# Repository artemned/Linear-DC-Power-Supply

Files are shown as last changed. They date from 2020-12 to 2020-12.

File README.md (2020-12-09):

# Linear-DC-Power-Supply
##  Board source dc voltage and dc current.   
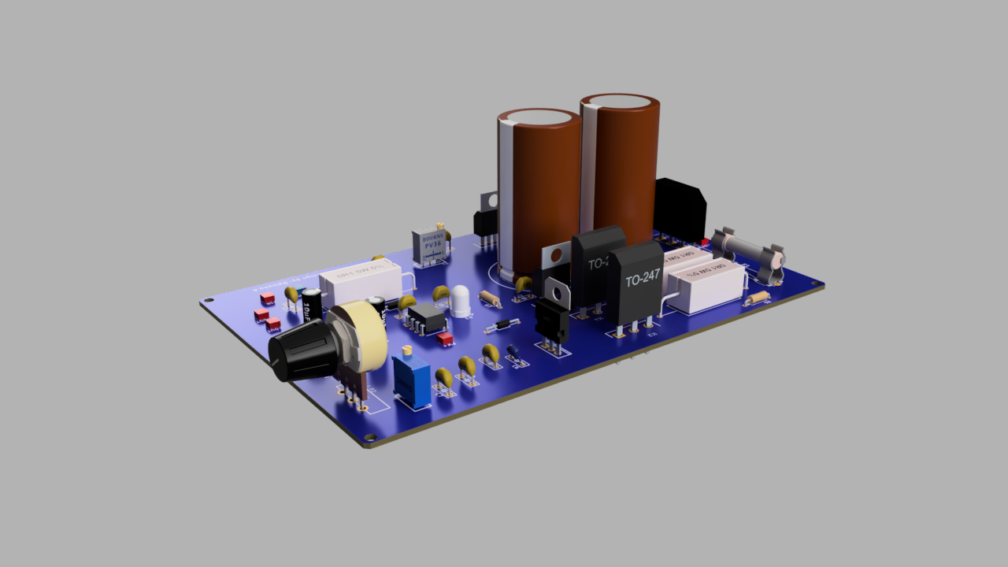
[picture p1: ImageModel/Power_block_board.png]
 

## One of the possible types power supplies
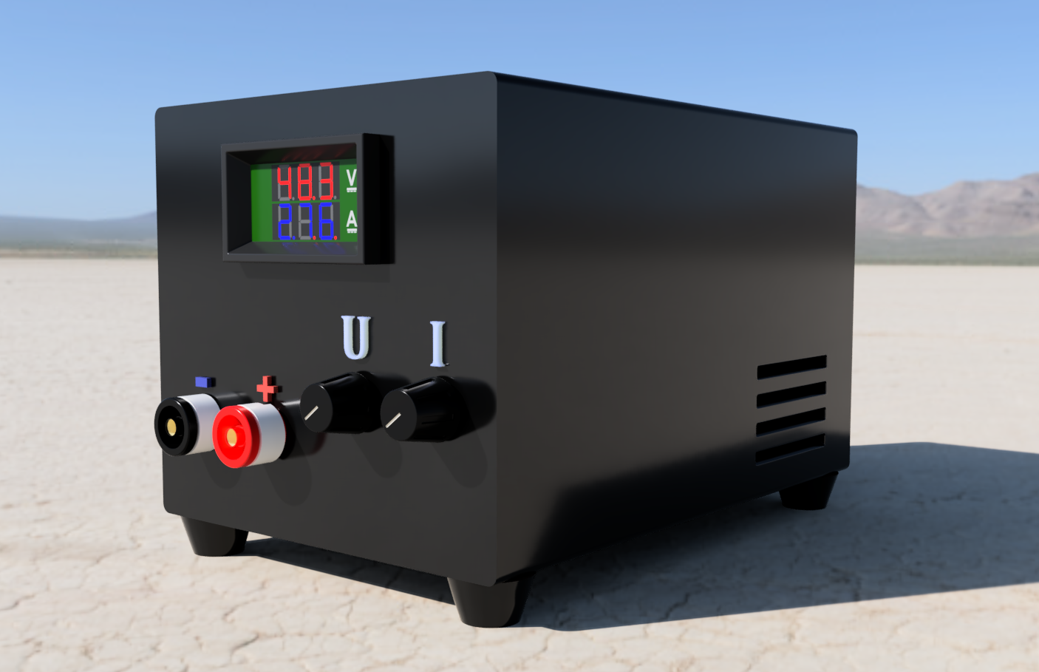
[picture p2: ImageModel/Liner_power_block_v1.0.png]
 
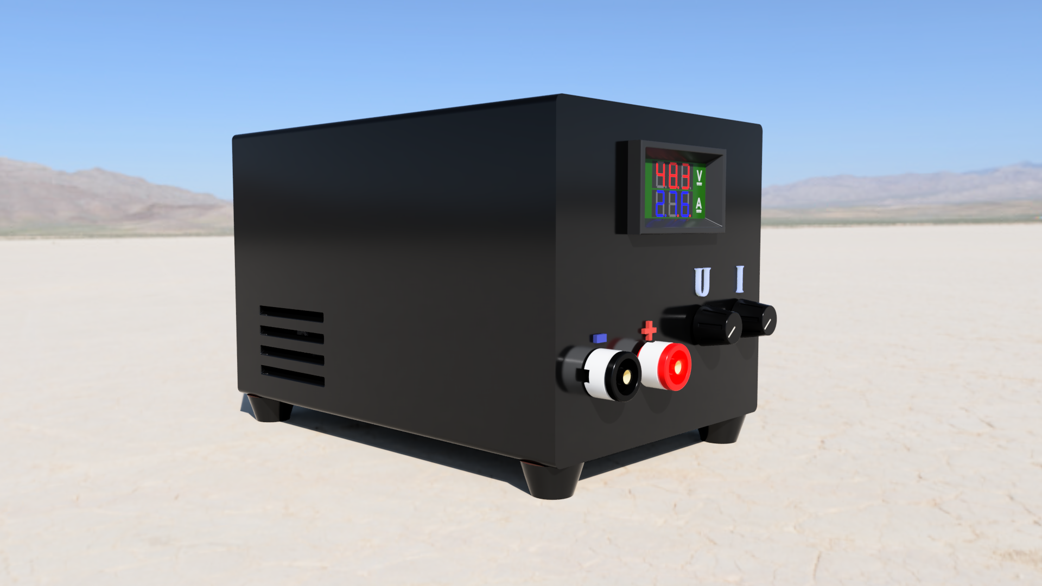
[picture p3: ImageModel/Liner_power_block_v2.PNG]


### I was inspired to create this project by the advice of my colleagues and the lack of a regulated DC voltage and DC power supply. I also wanted to practice PCB design. I used Eagle CAD for this. The project is based on one of the schematics in The Art of Circuitry by Paul Horowitz and Hill Winfield. There are many variants of this device on the network, but it seems to me that it is simpler and does not require many components. Of course, this scheme has a number of positive changes compared to the original. Everything you need to make a board and assemble a device is in the repository.I am sure that even a novice radio amateur will be able to assemble it, and if something suddenly does not work out, then write to the email address: daineko.a32@mail.ru.    P.S. All goodness and fresh cookies!

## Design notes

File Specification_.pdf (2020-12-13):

Part | Value | Package | Description
B1 | | FBU4 | Diode bridge GBU 8005
B2 | | FBU4 | Diode bridge GBU 8005
C1 | 10000uF | EB30D | Polarized capacitor
C2 | 10000uF | EB30D | Polarized capacitor
C3 | 68n | C050-025X075 | Capacitor
C4 | 0.33uF | C5B2.5 | Capacitor
C5 | 1.0uF | C050-025X075 | Capacitor
C6 | 100pF | C5B2.5 | Capacitor
C7 | 0.1uF | C5B2.5 | Capacitor
C8 | 100pF | C5B2.5 | Capacitor
C9 | 100pF | C5B2.5 | Capacitor
C10 | 10uF | CPOL-RADIAL-2.5MM-5MM | 10.0ВµF Polarized capacitors
C11 | 0.22uF | C5B2.5 | Capacitor
C12 | 10nF | C5B2.5 | Capacitor
C13 | 1000uF | EB22,5D | Polarized capacitor
C14 | 0.1uF | C5B2.5 | Capacitor
C15 | 10uF | CPOL-RADIAL-2.5MM-5MM | 10.0ВµF polarized capacitors
D1 | 1N5408RLG | DIOAD2860W130L840D505 | Diode
D2 | 1N914 | DIOAD1068W53L380D172 | Small Signal Diode
D3 | 1N914 | DIOAD1068W53L380D172 | Small Signal Diode
D4 | 1N5408RLG | DIOAD2860W130L840D505 | Diode
F1 | | FUSE | FUSE
IC1 | TIP36C | TO545P515X1560X2445-3P | PNP Bipolar Transistor, 25 A 100 V , 3-Pin TO-247
IC2 | TIP36C | TO545P515X1560X2445-3P | PNP Bipolar Transistor, 25 A 100 V , 3-Pin TO-247
IC3 | LM7812CT_NOPB | TO254P470X1028X1955-3P | LM7812CT Positive Voltage Regulator, 1A, 12 V, TO-220
IC4 | LM301AN_NOPB | DIP794W53P254L959H508Q8N | LM301AN/NOPB Op Amp, 8-Pin MDIP
IC5 | LM7905CT_NOPB | TO254P470X1028X1955-3P | LM7905CT Negative Voltage Reg 1.5A -5 V, 3-Pin TO-220
LED1 | SFH482 | SFH482 | IR LED
P1 | 470K | RTRIM3296W | Trimm resistor
P4 | 100 | RTRIM3296W | Trimm resistor
R1 | 30 2W | 0207/10 | Resistor
R2 | 0,1 5W | RESAD6200W85L2200D1000 | Wirewound Resistors - Through Hole SQP5 R10 5% WIRE
R3 | 0,1 5W | RESAD6200W85L2200D1000 | Wirewound Resistors - Through Hole SQP5 R10 5% WIRE
R4 | 680 | R1206 | Resistor
R5 | 0,1 5W | RESAD6200W85L2200D1000 | Wirewound Resistors - Through Hole SQP5 R10 5% WIRE
R6 | 330 2W | 0207/10 | Resistor
R7 | 220 | M1206 | Resistor
R8 | 220 | M1206 | Resistor
R9 | 200 | M1206 | Resistor
REG_I_P2 | 500K | POT_ALPHA_RV16AF-20
REG_U_P3 | 5.1K | POT_ALPHA_RV16AF-20
U1 | V_REG_317SINK | TO220-ADJ | Voltage Regulator

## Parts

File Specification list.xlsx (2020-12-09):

Position names | Components name | Quantity
B1,B2 | Diode bridge GBU 8005 | 2
С1,C2 | Capacitors 10000uf | 2
C3 | Capacitor ceramic 68n | 2
C4 | Capacitor ceramic 0.33uf | 1
C5 | Capacitor ceramic 1.0uf | 1
C6,C8,C9 | Capacitors ceramic 100pf | 3
C7,C14 | Capacitors ceramic 0,1uf | 2
C10,C15 | Capacitors 10uf | 2
C11 | Capacitor ceramic 0.22uf | 1
C12 | Capacitor ceramic 10nf | 1
C13 | Capacitor 1000uf | 1
D1,D4 | Diode 1N5408RLG | 2
D2,D3 | Diode 1N914 | 2
F1 | Fuse 5А/30В | 1
IC1,IC2 | Transistors TIP36C | 2
IC3 | Voltage regulator LM7812 | 1
IC4 | Single operationnal amplifier LM301A | 1
IC5 | Voltage regulator LM7905 | 1
LED1 | Signal diode | 1
P1 | Trimming potentiometer 470 kOhm | 1
P2 | Trimming potentiometer 500kOhm | 1
P3 | Trimming potentiometer 5,1 kOhm | 1
P4 | Trimming potentiometer 100 | 1
R1 | Resistor 30 2W | 1
R2,R3,R5 | Resistors 0,1 5W | 3
R4 | Resistor 680 | 1
R6 | Resistors 330 2W | 1
R7,R8 | Resistors 220 | 2
R9 | Resistor 200 | 1
U1 | Voltage regulator LM317К | 1

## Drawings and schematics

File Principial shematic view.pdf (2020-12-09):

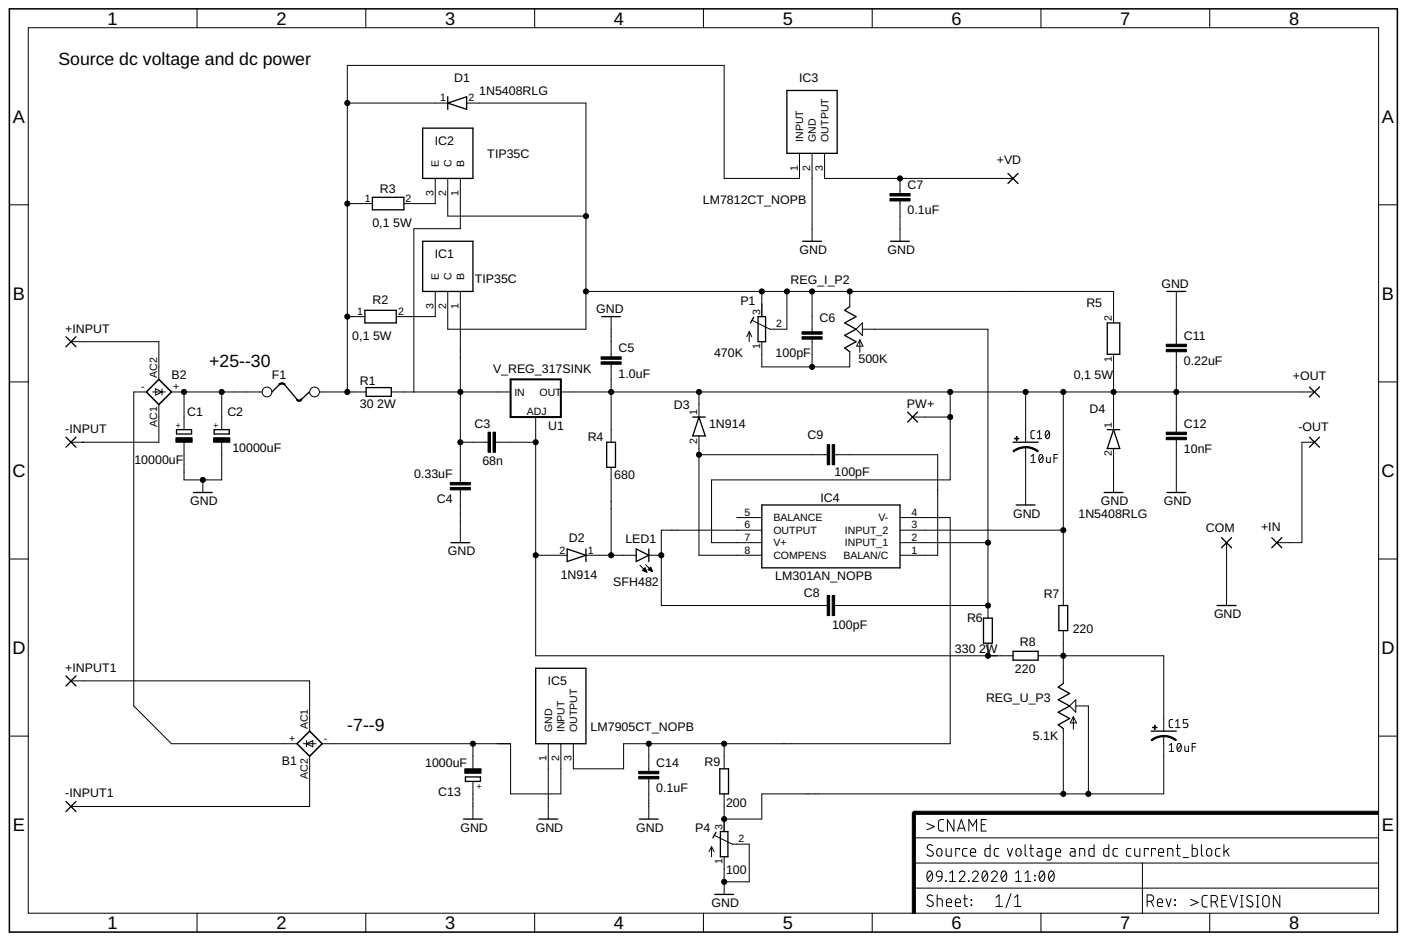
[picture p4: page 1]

Source dc voltage and dc power

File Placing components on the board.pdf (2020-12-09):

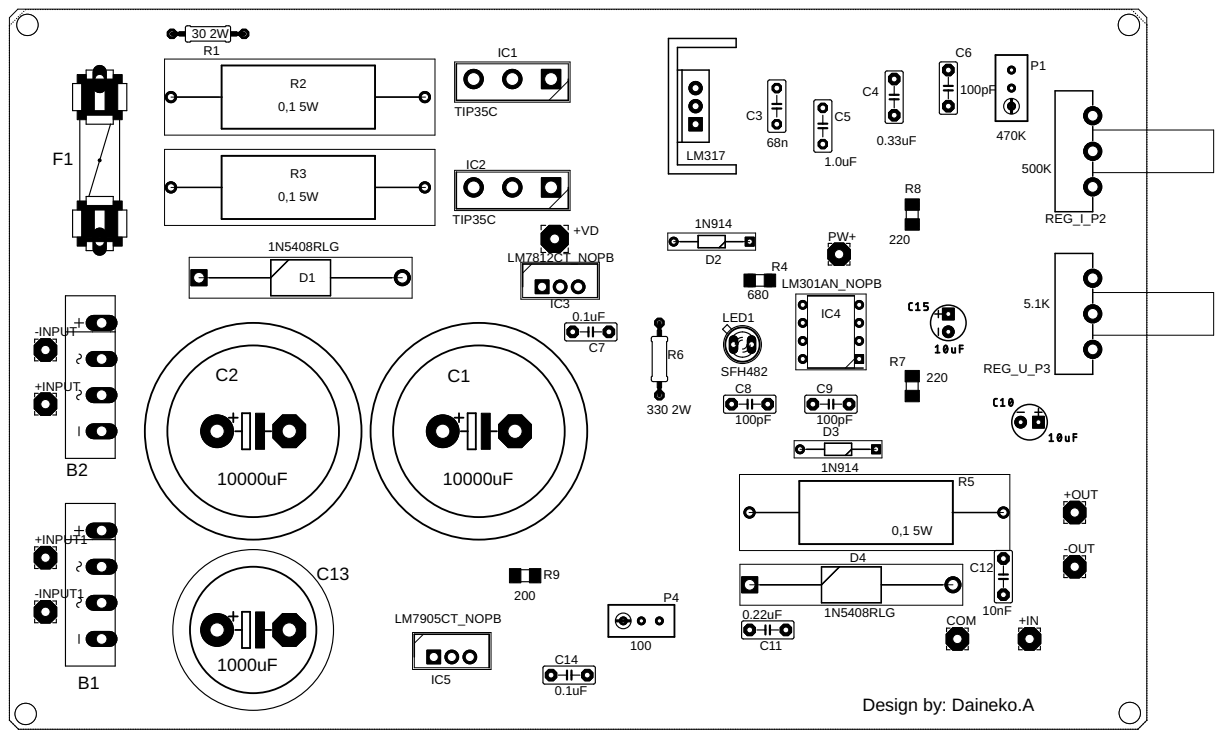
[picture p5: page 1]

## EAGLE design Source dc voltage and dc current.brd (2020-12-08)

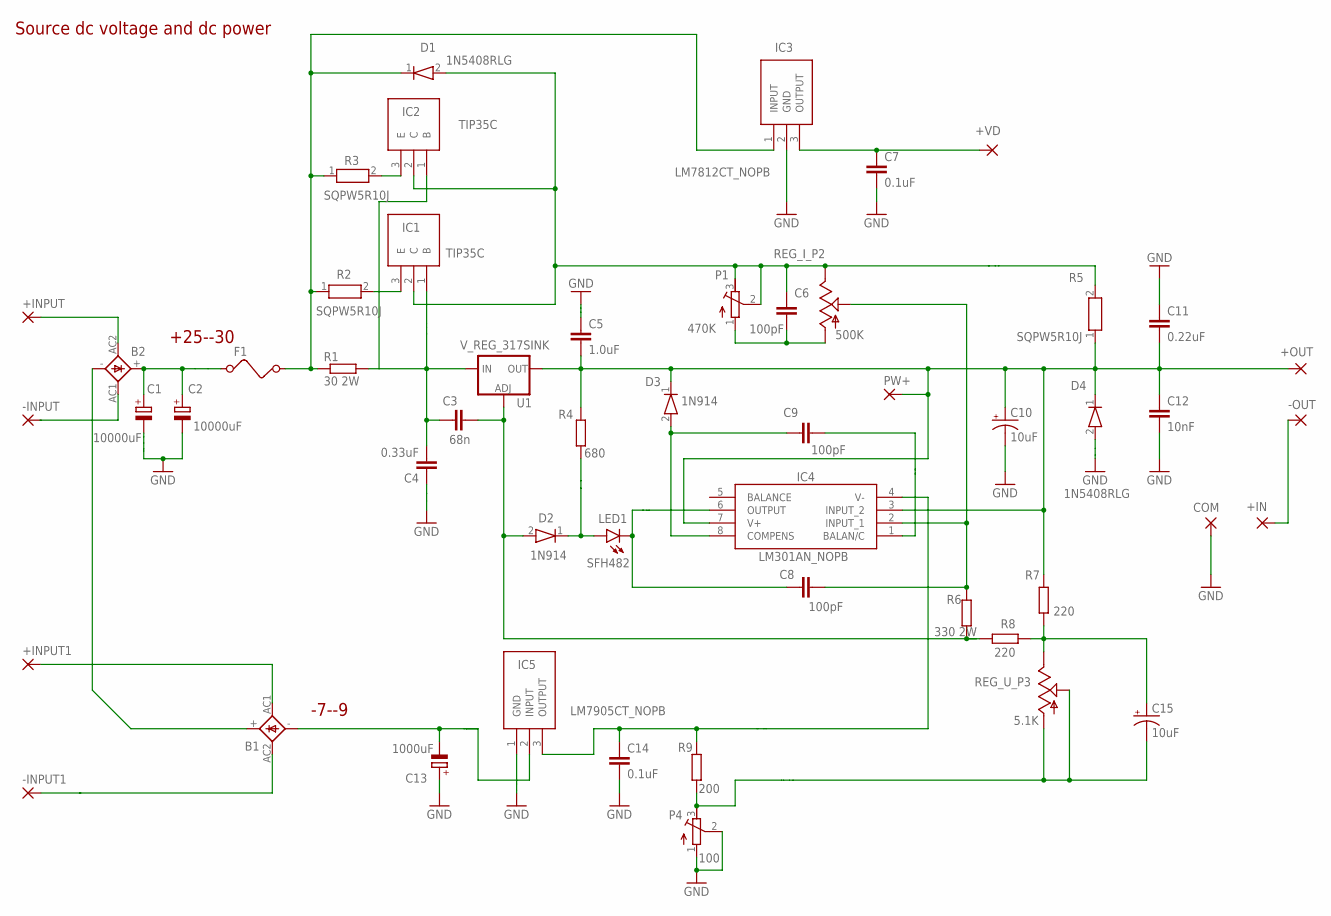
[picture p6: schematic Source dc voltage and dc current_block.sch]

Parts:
+IN: 3,17/1,3
+INPUT, +INPUT1: 3,17/1,3
+OUT: 3,17/1,3
+VD: 3,81/1,4
-INPUT, -INPUT1: 3,17/1,3
-OUT: 3,17/1,3
B1, B2: FBU4
C1, C2: 10000uF; EB30D
C3: 68n; C050-025X075
C4: 0.33uF; C5B2.5
C5: 1.0uF; C050-025X075
C6, C8, C9: 100pF; C5B2.5
C7, C14: 0.1uF; C5B2.5
C10, C15: 10uF; CPOL-RADIAL-2.5MM-5MM
C11: 0.22uF; C5B2.5
C12: 10nF; C5B2.5
C13: 1000uF; EB22,5D
COM: 3,17/1,3
D1, D4: 1N5408RLG; DIOAD2860W130L840D505
D2, D3: 1N914; DIOAD1068W53L380D172
F1: FUSE
IC1, IC2: TIP35C; TO545P515X1560X2445-3P
IC3: LM7812CT_NOPB; TO254P470X1028X1955-3P
IC4: LM301AN_NOPB; DIP794W53P254L959H508Q8N
IC5: LM7905CT_NOPB; TO254P470X1028X1955-3P
LED1: SFH482
P1: 470K; RTRIM3296W
P4: 100; RTRIM3296W
PW+: 3,17/1,3
R1: 30 2W; 0207/10
R2, R3, R5: SQPW5R10J; RESAD6200W85L2200D1000
R4: 680; R1206
R6: 330 2W; 0207/10
R7, R8: 220; M1206
R9: 200; M1206
REG_I_P2: 500K; POT_ALPHA_RV16AF-20
REG_U_P3: 5.1K; POT_ALPHA_RV16AF-20
U1: V_REG_317SINK; TO220-ADJ

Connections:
12V: D1.1 (K), F1.2, IC3.1 (INPUT), R1.1, R2.1, R3.1
GND: C1.-, C2.-, C4.1, C5.1, C7.2, C10.2 (-), C11.1, C12.2, C13.+, C14.2, COM.1, D4.2 (A), IC3.2 (GND), IC5.1 (GND), P4.1 (A), P4.2 (S)
IN+: +OUT.1, C5.2, C10.1 (+), C11.2, C12.1, D3.1 (K), D4.1 (K), IC4.3 (INPUT_2), IC4.7 (V+), PW+.1, R4.2, R5.1, R7.2, U1.OUT
IN-: C6.1, D1.2 (A), IC1.2 (C), IC2.2 (C), P1.2 (S), P1.3 (E), R5.2, REG_I_P2.3 (E)
unnamed: B2.+, C1.+, C2.+, F1.1
unnamed: +VD.1, C7.1, IC3.3 (OUTPUT)
unnamed: B1.-, C13.-, IC5.2 (INPUT)
unnamed: +IN.1, -OUT.1
unnamed: D2.1 (K), LED1.A, R4.1
unnamed: IC1.3 (E), R2.2
unnamed: -INPUT.1, B2.AC1 (AC2)
unnamed: IC2.3 (E), R3.2
unnamed: C6.2, P1.1 (A), REG_I_P2.1 (A)
unnamed: +INPUT.1, B2.AC2 (AC1)
unnamed: -INPUT1.1, B1.AC2 (AC1)
unnamed: +INPUT1.1, B1.AC1 (AC2)
unnamed: C15.1 (+), R7.1, R8.1, REG_U_P3.3 (E)
unnamed: C3.1, C4.2, IC1.1 (B), IC2.1 (B), R1.2, U1.IN
unnamed: C8.1, IC4.6 (OUTPUT), LED1.K (C)
unnamed: B1.+, B2.-
unnamed: C15.2 (-), P4.3 (E), R9.1, REG_U_P3.1 (A), REG_U_P3.2 (S)
unnamed: C9.1, D3.2 (A), IC4.8 (COMPENS)
unnamed: C9.2, IC4.1 (BALAN/C)
unnamed: C8.2, IC4.2 (INPUT_1), R6.2, REG_I_P2.2 (S)
OUT: C3.2, D2.2 (A), R6.1, R8.2, U1.ADJ
VE: C14.1, IC4.4 (V-), IC5.3 (OUTPUT), R9.2

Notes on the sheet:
+25--30
-7--9
Source dc voltage and dc power

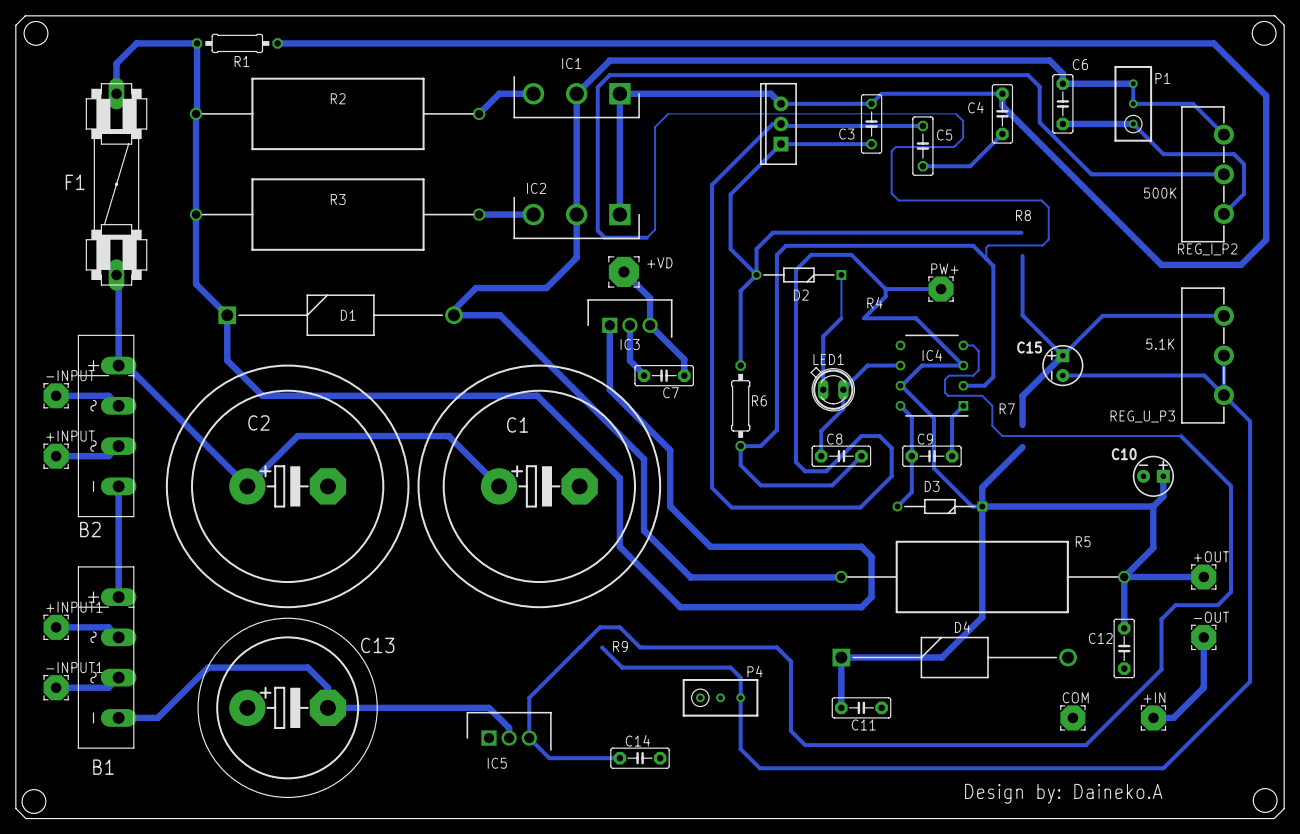
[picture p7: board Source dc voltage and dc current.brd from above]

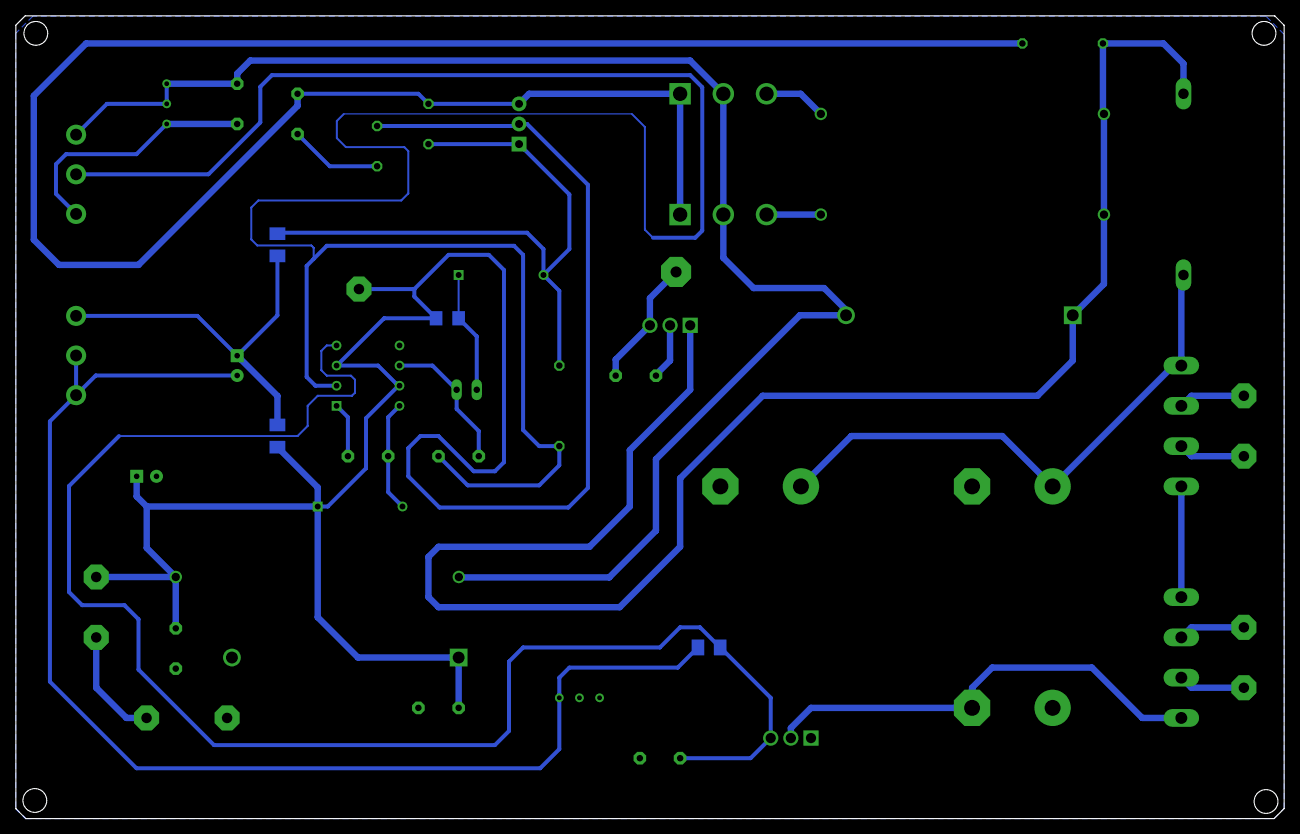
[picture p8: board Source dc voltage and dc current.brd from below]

Board: 2 copper layers, 160.0 x 101.3 mm, 52 parts (4 on the bottom side), 26 nets.

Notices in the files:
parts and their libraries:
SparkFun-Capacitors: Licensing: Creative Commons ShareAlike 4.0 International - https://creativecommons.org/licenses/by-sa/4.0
